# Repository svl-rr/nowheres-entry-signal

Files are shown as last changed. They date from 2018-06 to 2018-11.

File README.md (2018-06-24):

# SVL (Nowheres) Yard Entry Signal Driver

This is Arduino firmware for a microcontroller that has a pushbutton that
the yardmaster pushes to clear the signal. When the button is pressed,
the signal goes green for a constant amount of time and the buzzer plays
a chirping tone. After the time is up, the signal goes red again.

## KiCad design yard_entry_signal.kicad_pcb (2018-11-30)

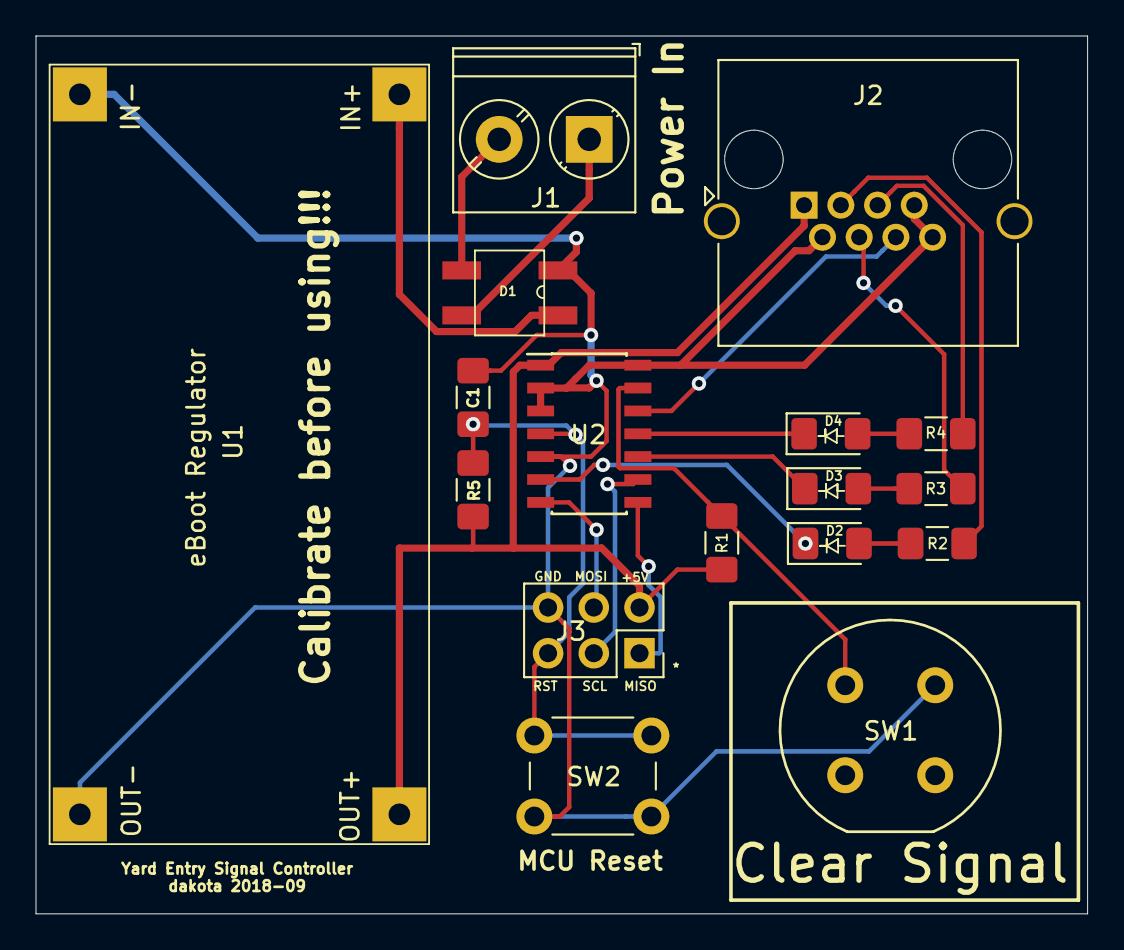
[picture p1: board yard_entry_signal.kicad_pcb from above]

Board: 2 copper layers, 58.4 x 48.8 mm, 17 parts (0 on the bottom side), 20 nets.

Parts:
C1: 10uF; C_1206_3216Metric_Pad1.42x1.75mm_HandSolder
D1: Rect; MBS
D2: Red; LED_1206_HandSolder_Marked
D3: Yellow; LED_1206_HandSolder_Marked
D4: Green; LED_1206_HandSolder_Marked
J1: Conn_01x02; TerminalBlock_Phoenix_PT-1,5-2-5.0-H_1x02_P5.00mm_Horizontal
J2: RJ45; RJ45_Amphenol_RJHSE5380
J3: AVR-ISP-6; PinSocket_2x03_P2.54mm_Vertical
R1, R5: 10k; R_1206_3216Metric_Pad1.42x1.75mm_HandSolder
R2, R3, R4: 390; R_1206_3216Metric_Pad1.42x1.75mm_HandSolder
SW1: UsrBtn; Push_E-Switch_KS01Q01
SW2: Reset; SW_PUSH_6mm_H5mm
U1: eboot_regulator
U2: ATtiny44A-SSU; SOIC-14_3.9x8.7mm_P1.27mm

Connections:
+5V: J2.1, J3.2, R1.1, R5.2, U1.3, U2.1
/AC_PWR_1: D1.4, J1.2
/AC_PWR_2: D1.3, J1.1
/ATTiny44A/PA0: R1.2, SW1.1, U2.13
/ATTiny44A/PA2: D4.1, U2.11
/ATTiny44A/PA3: D3.1, U2.10
/ATTiny44A/PA7: D2.1, U2.6
/ATTiny44A/RESET_PB3: C1.1, J3.5, R5.1, SW2.1, U2.4
/ATTiny44A/SPI_MISO_PA5: J3.1, U2.8
/ATTiny44A/SPI_MOSI_PA6: J3.4, U2.7
/ATTiny44A/SPI_SCL_PA4: J3.3, U2.9
/Yard Signal Jack/Buzzer: J2.6, U2.12
/Yard Signal Jack/Green_Drain: J2.5, R4.2
/Yard Signal Jack/Red_Drain: J2.3, R2.2
/Yard Signal Jack/Yellow_Drain: J2.4, R3.2
GND: C1.2, D1.2, J2.2, J2.7, J2.8, J3.6, SW1.2, SW2.2, U1.2, U1.4, U2.2, U2.3, U2.5, U2.14
unnamed: D1.1, U1.1
unnamed: D2.2, R2.1
unnamed: D3.2, R3.1
unnamed: D4.2, R4.1

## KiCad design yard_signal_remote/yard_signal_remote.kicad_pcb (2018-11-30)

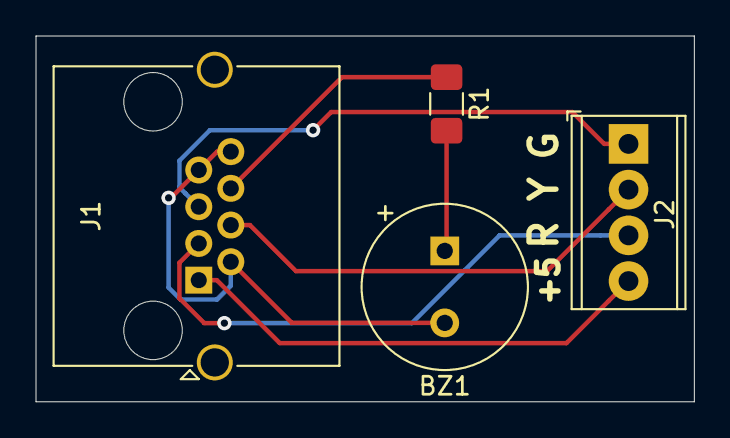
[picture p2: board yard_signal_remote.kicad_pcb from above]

Board: 2 copper layers, 36.6 x 20.3 mm, 4 parts (0 on the bottom side), 7 nets.

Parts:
BZ1: Buzzer; MagneticBuzzer_CUI_CST-931RP-A
J1: RJ45; RJ45_Amphenol_RJHSE5380
J2: Conn_01x04_Female; TerminalBlock_Phoenix_MPT-0,5-4-2.54_1x04_P2.54mm_Horizontal
R1: 100; R_1206_3216Metric_Pad1.42x1.75mm_HandSolder

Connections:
+5V: J1.1, J2.4
/Buzzer: J1.6, R1.1
/Green_Drain: J1.5, J2.1
/Red_Drain: J1.3, J2.3
/Yellow_Drain: J1.4, J2.2
GND: BZ1.2, J1.2, J1.7, J1.8
unnamed: BZ1.1, R1.2

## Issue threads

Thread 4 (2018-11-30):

Confusing which way button goes

szabodabo, 2018-11-30:
Pins are shorted along perforated sides of button [EG4793-ND](https://www.digikey.com/products/en?keywords=eg4793-nd) . Add silkscreen marker to indicate placement.

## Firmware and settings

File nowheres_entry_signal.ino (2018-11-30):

#define SIGNAL_RED_PIN 7  // PA7, Tiny 6
#define SIGNAL_YELLOW_PIN 3  // PA3, Tiny 10
#define SIGNAL_GREEN_PIN 2  // PA2, Tiny 11
#define BUZZER_PIN 1  // Tiny 12
#define BUTTON_PIN 0 // PA0, Tiny 13
// #define LED_L_PIN 13

#define GREEN_TIME_MS 25000
#define YELLOW_TIME_MS 0  // disabled for now

#define BUZZER_NOTE_LENGTH_MS 20
#define BUZZER_REST_LENGTH_MS 50
#define BUZZER_TOTAL_SONG_LENGTH_MS 2000
#define BUZZER_PERIOD_MS (BUZZER_NOTE_LENGTH_MS + BUZZER_REST_LENGTH_MS)

unsigned long buttonPressedMs = 0;
unsigned short buzzerNoteAndRestStartTimeMs = 0;

void SetSignal(const int onPin) {
  digitalWrite(SIGNAL_RED_PIN, HIGH);
  digitalWrite(SIGNAL_YELLOW_PIN, HIGH);
  digitalWrite(SIGNAL_GREEN_PIN, HIGH);
  digitalWrite(onPin, LOW);
}

void PokeBuzzer(const unsigned long now_ms) {
  unsigned long msSinceButtonPress = now_ms - buttonPressedMs;
  if (buttonPressedMs > 0 && msSinceButtonPress < BUZZER_TOTAL_SONG_LENGTH_MS) {
    if (buzzerNoteAndRestStartTimeMs == 0) {
      buzzerNoteAndRestStartTimeMs = now_ms;
    }

    unsigned long currentNoteDurationMs = now_ms - buzzerNoteAndRestStartTimeMs;
    if (currentNoteDurationMs < BUZZER_NOTE_LENGTH_MS) {
      digitalWrite(BUZZER_PIN, HIGH);
    } else if (currentNoteDurationMs < BUZZER_PERIOD_MS) {
      digitalWrite(BUZZER_PIN, LOW);
    } else {
      // start a new note
      buzzerNoteAndRestStartTimeMs = 0;
    }
  } else {
    buzzerNoteAndRestStartTimeMs = 0;
    digitalWrite(BUZZER_PIN, LOW);
  }
}

void setup() {
  pinMode(SIGNAL_RED_PIN, OUTPUT);
  pinMode(SIGNAL_YELLOW_PIN, OUTPUT);
  pinMode(SIGNAL_GREEN_PIN, OUTPUT);
  pinMode(BUZZER_PIN, OUTPUT);
  pinMode(BUTTON_PIN, INPUT_PULLUP);
  // pinMode(LED_L_PIN, OUTPUT);

  SetSignal(SIGNAL_RED_PIN);
}

void loop() {
  unsigned long now_ms = millis();
  if (digitalRead(BUTTON_PIN) == LOW) { // active
    buttonPressedMs = now_ms;
    // digitalWrite(LED_L_PIN, HIGH);
    SetSignal(SIGNAL_GREEN_PIN);
  } else {
    // digitalWrite(LED_L_PIN, LOW);
  }

  PokeBuzzer(now_ms);

  unsigned long msSinceButtonPress = now_ms - buttonPressedMs;
  if (msSinceButtonPress > (GREEN_TIME_MS + YELLOW_TIME_MS)) {
    SetSignal(SIGNAL_RED_PIN);
  } else if (msSinceButtonPress > GREEN_TIME_MS) {
    SetSignal(SIGNAL_YELLOW_PIN);
  }
}

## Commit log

2018-06-24 Initial commit for rev 0 of nowheres yard entry signal driver
2018-11-30 Add PCBs for yard signal project
    [attiny44a.sch, yard_entry_signal.kicad_pcb, yard_entry_signal.sch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]
